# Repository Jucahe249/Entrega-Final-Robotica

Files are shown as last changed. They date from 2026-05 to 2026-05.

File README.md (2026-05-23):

En cada una de las carpetas hay una parte importante de Resqube

la carpeta RES contiene un modo de manejo de resqube que corresponde a una teleoperacion via teclado del pc y micro ros

la carpeta Resqube ensamblaje presenta todo el URDF de Resqube que fue necesario para su posterior implementacion en gazebo y en Rviz

El archivo comprimido Resqube.zip corresponde a esa configuracion en Gazebo y en Rviz donde se simulo a Resqube 

El archivo Resqube sin comprimir contiene los modelos cad de solid works que corresponden a los del Gazebo y Rviz

finalmente la carpeta resqube_ros2 corresponde a la alternativa principal de control de Resqube que es la teleoperacion por medio de una 
URL que se encarga de generar los comandos en Ros para que microros los interprete y se comunique con la ESP32

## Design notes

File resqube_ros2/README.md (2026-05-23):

# RESQUBE ROS2

## Estructura
```
resqube_ros2/
├── firmware/
│   ├── platformio.ini
│   └── resqube_firmware/
│       └── resqube_firmware.ino     ← flashear al ESP32
└── ros2_ws/
    └── src/resqube_ros2/
        ├── package.xml
        ├── CMakeLists.txt
        ├── resqube_ros2/
        │   ├── corridor_follower.py ← modo autónomo
        │   ├── teleop_joy.py        ← control por teclado
        │   └── alert_monitor.py     ← monitor de alertas
        ├── launch/
        │   └── resqube.launch.py    ← lanza todo
        └── config/
            └── rviz_resqube.rviz
```

## Requisitos
- ROS2 Humble
- micro-ROS Agent: `sudo apt install ros-humble-micro-ros-agent`
- PlatformIO con lib micro_ros_arduino
- ESP32 DevKit V1

## Instalación del workspace
```bash
cd ros2_ws
rosdep install --from-paths src --ignore-src -r -y
colcon build --packages-select resqube_ros2
source install/setup.bash
```

## Configurar el firmware
Editar en resqube_firmware.ino:
```cpp
#define WIFI_SSID  "TU_RED_WIFI"
#define WIFI_PASS  "TU_PASSWORD"
#define AGENT_IP   "192.168.1.100"   // IP de tu PC
#define AGENT_PORT 8888
```
Flashear con PlatformIO:
```bash
cd firmware
pio run --target upload
```

## Ejecutar
```bash
# Terminal 1 — todo de una vez:
ros2 launch resqube_ros2 resqube.launch.py

# O manualmente:
# T1 — agente
ros2 run micro_ros_agent micro_ros_agent udp4 --port 8888
# T2 — seguidor autónomo
ros2 run resqube_ros2 corridor_follower.py
# T3 — alertas
ros2 run resqube_ros2 alert_monitor.py
# T4 — teclado
ros2 run resqube_ros2 teleop_joy.py
```

## Verificar conexión
```bash
ros2 topic list          # debe mostrar /scan /cmd_vel /object_alert
ros2 topic hz /scan      # debe mostrar ~20 Hz
ros2 topic echo /scan    # ver datos en tiempo real
```

## Cambiar modo desde terminal
```bash
# Activar autónomo
ros2 service call /corridor_follower/activate std_srvs/srv/SetBool "{data: true}"
# Volver a remoto
ros2 service call /corridor_follower/activate std_srvs/srv/SetBool "{data: false}"
```

## Teleop desde teclado (en teleop_joy.py)
  W/S = adelante/atrás
  A/D = izquierda/derecha
  ESPACIO = stop
  X = activar servo
  M = toggle modo autónomo
  Q = salir

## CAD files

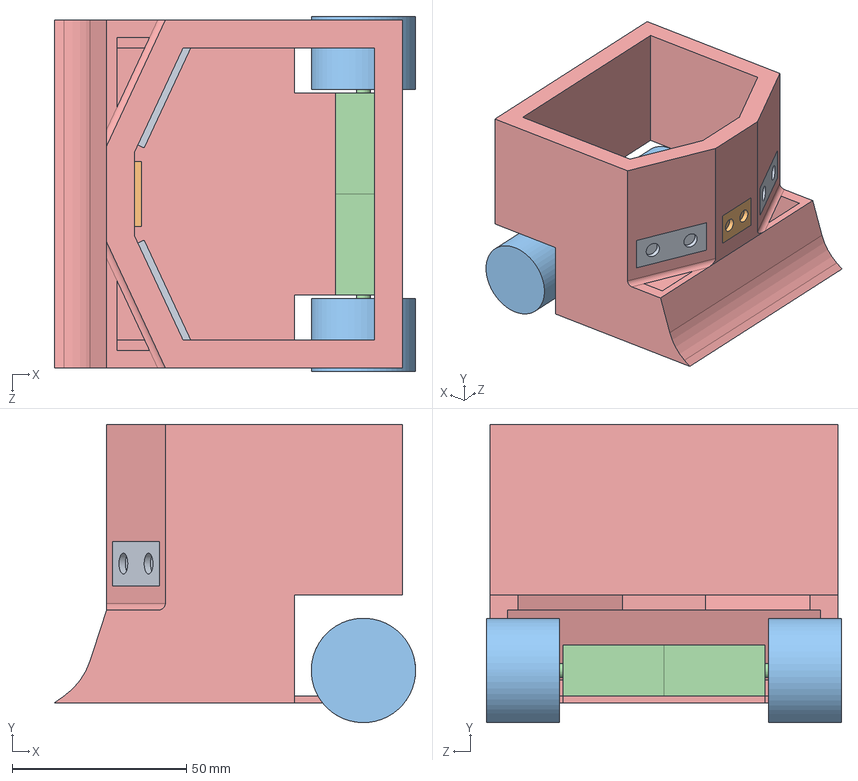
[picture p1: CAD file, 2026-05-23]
Resqube/Resqube.SLDASM
103.8 x 85.7 x 102.0 mm
Futsumo2
motor_resqube x 2
Rueda_resqube x 2
Sensor_frontal
Sensor_lateral x 2

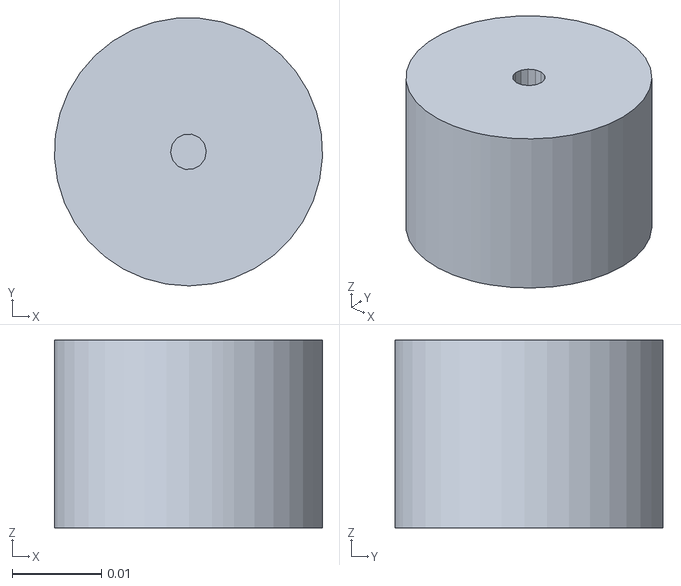
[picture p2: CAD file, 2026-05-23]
Resqube/Resqube_ensamblaje/meshes/rueda_izq_Link.STL
0.03 x 0.03 x 0.021

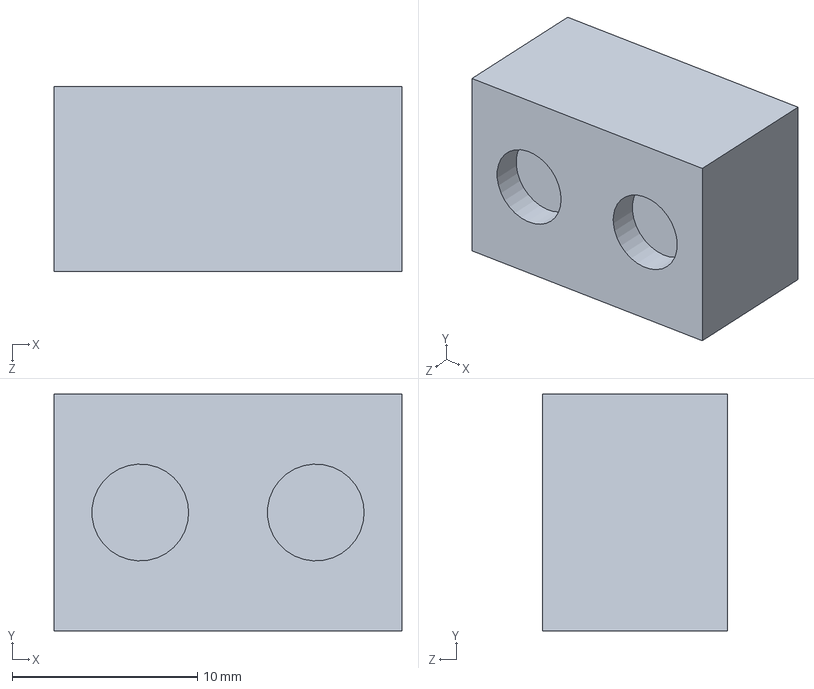
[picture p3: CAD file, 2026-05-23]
Resqube/Sensor_frontal.SLDPRT
18.8 x 12.8 x 10.0 mm

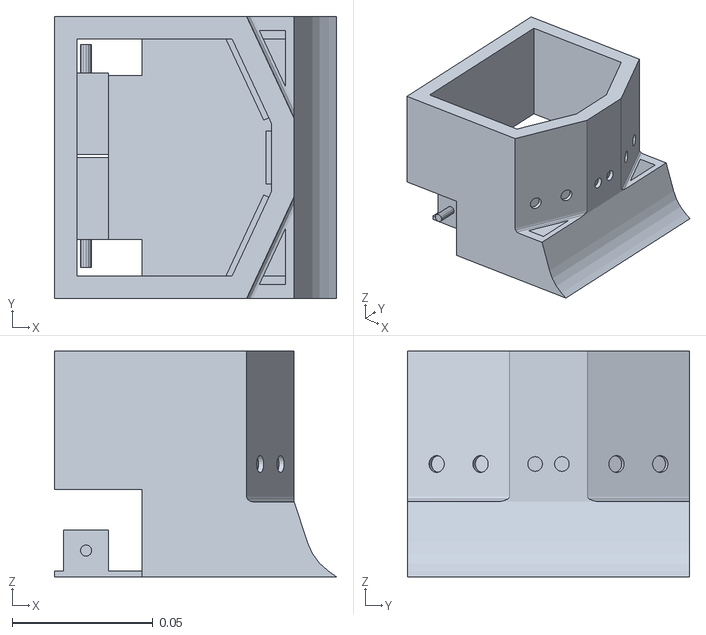
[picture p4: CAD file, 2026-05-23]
Resqube/Resqube_ensamblaje/meshes/base_link.STL
0.1 x 0.1 x 0.08

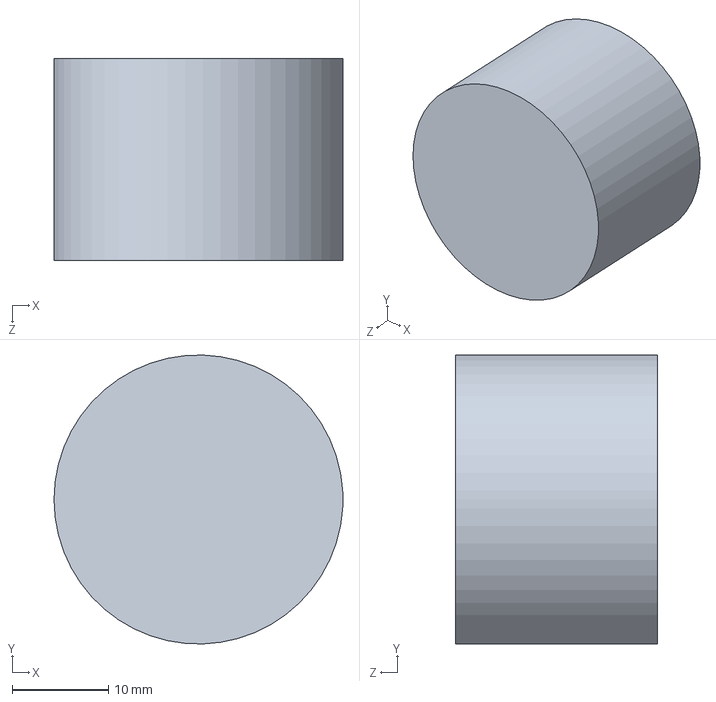
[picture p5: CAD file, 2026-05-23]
Resqube/Rueda_resqube.SLDPRT
30.0 x 30.0 x 21.0 mm

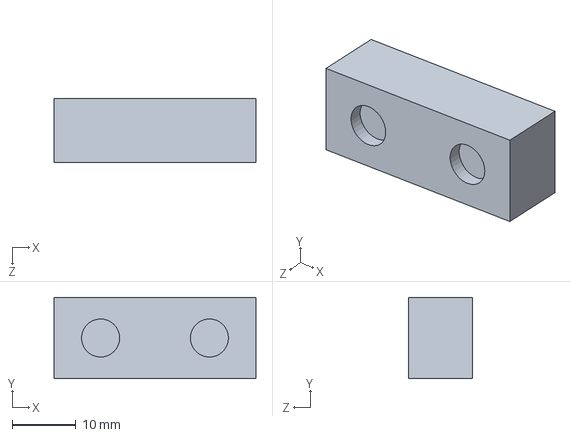
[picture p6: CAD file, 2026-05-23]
Resqube/Sensor_lateral.SLDPRT
31.8 x 12.8 x 10.0 mm

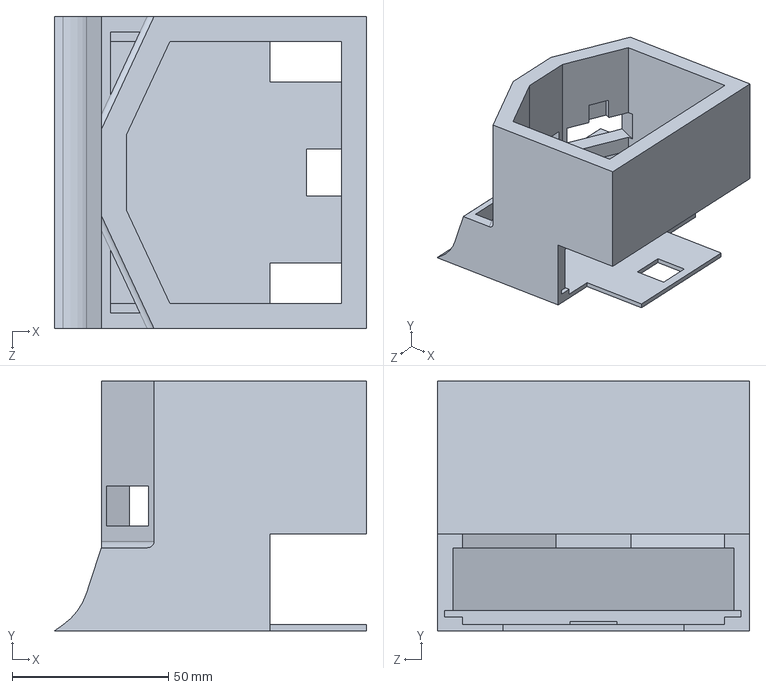
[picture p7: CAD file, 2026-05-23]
Resqube/Futsumo2.SLDPRT
100.0 x 80.0 x 100.0 mm

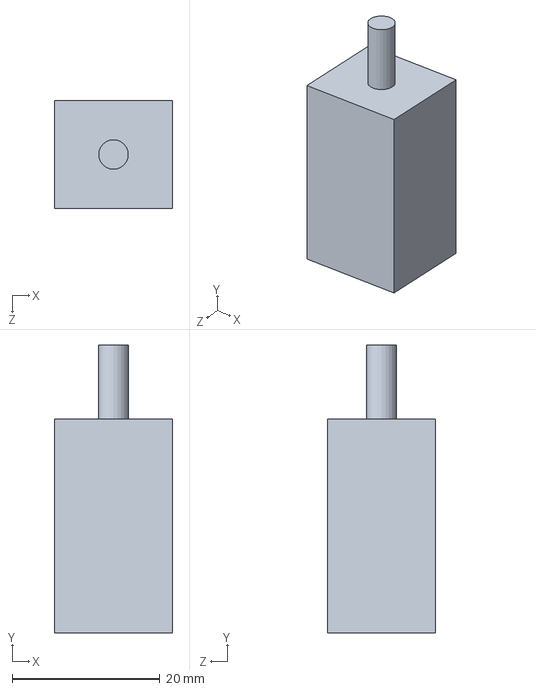
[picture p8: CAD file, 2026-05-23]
Resqube/motor_resqube.SLDPRT
16.0 x 39.0 x 14.6 mm

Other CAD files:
Resqube/Resqube_ensamblaje.SLDASM
Resqube/Resqube_ensamblaje/meshes/rueda_der_Link.STL

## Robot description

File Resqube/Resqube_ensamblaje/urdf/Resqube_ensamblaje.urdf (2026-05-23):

<?xml version="1.0" encoding="utf-8"?>
<!-- This URDF was automatically created by SolidWorks to URDF Exporter! Originally created by Stephen Brawner (brawner@gmail.com) 
     Commit Version: 1.6.0-4-g7f85cfe  Build Version: 1.6.7995.38578
     For more information, please see http://wiki.ros.org/sw_urdf_exporter -->
<robot name="Resqube_ensamblaje">
  <link name="base_link">
    <inertial>
      <origin xyz="-0.0077226 2.2038E-05 0.039426" rpy="0 0 0" />
      <mass value="0.18039" />
      <inertia ixx="0.00029984" ixy="5.4554E-08" ixz="3.0558E-05" iyy="0.00023582" iyz="-1.1356E-07" izz="0.00035246" />
    </inertial>
    <visual>
      <origin xyz="0 0 0" rpy="0 0 0" />
      <geometry>
        <mesh filename="package://Resqube_ensamblaje/meshes/base_link.STL" />
      </geometry>
      <material name="">
        <color rgba="0.79216 0.81961 0.93333 1" />
      </material>
    </visual>
    <collision>
      <origin xyz="0 0 0" rpy="0 0 0" />
      <geometry>
        <mesh filename="package://Resqube_ensamblaje/meshes/base_link.STL" />
      </geometry>
    </collision>
  </link>
  <link name="rueda_der_Link">
    <inertial>
      <origin xyz="3.8164E-17 -6.9389E-18 -0.009453" rpy="0 0 0" />
      <mass value="0.014718" />
      <inertia ixx="1.3755E-06" ixy="-1.0588E-22" ixz="-4.412E-23" iyy="1.3755E-06" iyz="2.7363E-23" izz="1.6697E-06" />
    </inertial>
    <visual>
      <origin xyz="0 0 0" rpy="0 0 0" />
      <geometry>
        <mesh filename="package://Resqube_ensamblaje/meshes/rueda_der_Link.STL" />
      </geometry>
      <material name="">
        <color rgba="0.79216 0.81961 0.93333 1" />
      </material>
    </visual>
    <collision>
      <origin xyz="0 0 0" rpy="0 0 0" />
      <geometry>
        <mesh filename="package://Resqube_ensamblaje/meshes/rueda_der_Link.STL" />
      </geometry>
    </collision>
  </link>
  <joint name="rueda_der_joint" type="continuous">
    <origin xyz="-0.038712 -0.05 0.0073" rpy="1.5708 -0.59492 0" />
    <parent link="base_link" />
    <child link="rueda_der_Link" />
    <axis xyz="0 0 1" />
    <limit effort="100" velocity="100" />
    <dynamics damping="0.1" friction="0.1" />
  </joint>
  <link name="rueda_izq_Link">
    <inertial>
      <origin xyz="1.3878E-17 -2.6021E-17 -0.010547" rpy="0 0 0" />
      <mass value="0.014718" />
      <inertia ixx="1.3755E-06" ixy="0" ixz="1.0421E-22" iyy="1.3755E-06" iyz="-1.2799E-22" izz="1.6697E-06" />
    </inertial>
    <visual>
      <origin xyz="0 0 0" rpy="0 0 0" />
      <geometry>
        <mesh filename="package://Resqube_ensamblaje/meshes/rueda_izq_Link.STL" />
      </geometry>
      <material name="">
        <color rgba="0.79216 0.81961 0.93333 1" />
      </material>
    </visual>
    <collision>
      <origin xyz="0 0 0" rpy="0 0 0" />
      <geometry>
        <mesh filename="package://Resqube_ensamblaje/meshes/rueda_izq_Link.STL" />
      </geometry>
    </collision>
  </link>
  <joint name="rueda_izq_joint" type="continuous">
    <origin xyz="-0.038712 0.031 0.0073" rpy="1.5708 1.3691 0" />
    <parent link="base_link" />
    <child link="rueda_izq_Link" />
    <axis xyz="0 0 -1" />
    <limit effort="100" velocity="100" />
    <dynamics damping="0.1" friction="0.1" />
  </joint>
</robot>

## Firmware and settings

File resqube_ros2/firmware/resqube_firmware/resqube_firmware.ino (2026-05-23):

/*
  ============================================
  RESQUBE - ESP32 DevKit V1
  micro-ROS client para ROS2 Humble
  Transport: WiFi UDP
  ============================================
  Topics publicados:
    /scan          sensor_msgs/LaserScan  (3 rayos Sharp)
    /line_sensor   std_msgs/Int32         (QTR raw)
    /object_alert  std_msgs/Bool          (sin paredes)
    /odom          nav_msgs/Odometry      (estimación básica)

  Topics suscritos:
    /cmd_vel       geometry_msgs/Twist
    /servo_cmd     std_msgs/Bool

  Servicios:
    /set_mode      std_srvs/SetBool       (true=AUTONOMO)
  ============================================
*/

#include <micro_ros_arduino.h>
#include <stdio.h>
#include <rcl/rcl.h>
#include <rcl/error_handling.h>
#include <rclc/rclc.h>
#include <rclc/executor.h>

#include <geometry_msgs/msg/twist.h>
#include <sensor_msgs/msg/laser_scan.h>
#include <std_msgs/msg/int32.h>
#include <std_msgs/msg/bool.h>
#include <nav_msgs/msg/odometry.h>
#include <std_srvs/srv/set_bool.h>

#include <ESP32Servo.h>

// ─── WIFI / AGENTE ────────────────────────────────────
#define WIFI_SSID   "TU_RED_WIFI"
#define WIFI_PASS   "TU_PASSWORD"
#define AGENT_IP    "192.168.251.131"   // IP de tu PC con el agente
#define AGENT_PORT  8888

// ─── PINES MOTOR A ────────────────────────────────────
#define PWMA   33
#define AIN1   14
#define AIN2   27

// ─── PINES MOTOR B ────────────────────────────────────
#define PWMB   32
#define BIN1   26
#define BIN2   25

// ─── SENSORES SHARP ───────────────────────────────────
#define SENSOR_IZQ     4
#define SENSOR_FRENTE  18
#define SENSOR_DER     19

// ─── SENSOR LÍNEA ─────────────────────────────────────
#define LINEA_DEL  35

// ─── OTROS ────────────────────────────────────────────
#define STBY      12
#define LED_PIN    2
#define SERVO_PIN 13

// ─── PWM ──────────────────────────────────────────────
#define PWM_FREQ    1000
#define PWM_RES     8
#define CHANNEL_A   0
#define CHANNEL_B   1

// ─── VELOCIDADES ──────────────────────────────────────
#define VEL_AVANCE      200
#define VEL_GIRO        180
#define VEL_CORRECCION  160
#define VEL_RETRO       200

// ─── UMBRAL QTR ───────────────────────────────────────
#define UMBRAL_QTR 2000

// ─── DISTANCIAS SHARP (metros) ────────────────────────
// GP2Y0A21 detecta ~10-80 cm. HIGH = objeto detectado
#define DIST_DETECTED   0.15f   // objeto a ~15 cm
#define DIST_CLEAR      1.0f    // pasillo libre

// ─── PUBLICACIÓN ──────────────────────────────────────
#define PUB_PERIOD_MS   50      // 20 Hz

// ─── micro-ROS handles ────────────────────────────────
rcl_node_t           node;
rclc_support_t       support;
rcl_allocator_t      allocator;
rclc_executor_t      executor;
rcl_timer_t          pub_timer;

rcl_subscription_t   sub_cmdvel;
rcl_subscription_t   sub_servo;
rcl_publisher_t      pub_scan;
rcl_publisher_t      pub_line;
rcl_publisher_t      pub_alert;
rcl_publisher_t      pub_odom;
rcl_service_t        srv_setmode;

geometry_msgs__msg__Twist          msg_cmdvel;
std_msgs__msg__Bool                msg_servo;
sensor_msgs__msg__LaserScan        msg_scan;
std_msgs__msg__Int32               msg_line;
std_msgs__msg__Bool                msg_alert;
nav_msgs__msg__Odometry            msg_odom;
std_srvs__srv__SetBool_Request     req_setmode;
std_srvs__srv__SetBool_Response    res_setmode;

// Buffer para LaserScan (3 rayos)
float scan_ranges[3];
float scan_intensities[3];

// ─── ESTADO ───────────────────────────────────────────
bool modoAutonomo = false;
bool alertaObjeto = false;
Servo miServo;

// ─── MACROS RCCHECK ───────────────────────────────────
#define RCCHECK(fn) { rcl_ret_t temp_rc = fn; if(temp_rc != RCL_RET_OK){ error_loop(); }}
#define RCSOFTCHECK(fn) { rcl_ret_t temp_rc = fn; if(temp_rc != RCL_RET_OK){} }

void error_loop() {
  while(1) {
    digitalWrite(LED_PIN, !digitalRead(LED_PIN));
    delay(100);
  }
}

// ══════════════════════════════════════════════════════
//  MOTORES (igual que antes)
// ══════════════════════════════════════════════════════

void motorsInit() {
  pinMode(AIN1, OUTPUT); pinMode(AIN2, OUTPUT);
  pinMode(BIN1, OUTPUT); pinMode(BIN2, OUTPUT);
  pinMode(STBY, OUTPUT);
  ledcSetup(CHANNEL_A, PWM_FREQ, PWM_RES);
  ledcAttachPin(PWMA, CHANNEL_A);
  ledcSetup(CHANNEL_B, PWM_FREQ, PWM_RES);
  ledcAttachPin(PWMB, CHANNEL_B);
  digitalWrite(STBY, HIGH);
}

void motorA_adelante(int v) { digitalWrite(AIN1,LOW);  digitalWrite(AIN2,HIGH); ledcWrite(CHANNEL_A,v); }
void motorA_atras(int v)    { digitalWrite(AIN1,HIGH); digitalWrite(AIN2,LOW);  ledcWrite(CHANNEL_A,v); }
void motorA_stop()          { digitalWrite(AIN1,LOW);  digitalWrite(AIN2,LOW);  ledcWrite(CHANNEL_A,0); }
void motorB_adelante(int v) { digitalWrite(BIN1,LOW);  digitalWrite(BIN2,HIGH); ledcWrite(CHANNEL_B,v); }
void motorB_atras(int v)    { digitalWrite(BIN1,HIGH); digitalWrite(BIN2,LOW);  ledcWrite(CHANNEL_B,v); }
void motorB_stop()          { digitalWrite(BIN1,LOW);  digitalWrite(BIN2,LOW);  ledcWrite(CHANNEL_B,0); }

void moverAdelante(int v) { motorA_atras(v);    motorB_atras(v);    }
void moverAtras(int v)    { motorA_adelante(v); motorB_adelante(v); }
void girarIzq(int v)      { motorA_atras(v);    motorB_adelante(v); }
void girarDer(int v)      { motorA_adelante(v); motorB_atras(v);    }
void stopMotors()         { motorA_stop();      motorB_stop();      }

// Convierte Twist a comandos de motor
void aplicarTwist(float linear, float angular) {
  if (linear > 0.05f)        moverAdelante(VEL_AVANCE);
  else if (linear < -0.05f)  moverAtras(VEL_AVANCE);
  else if (angular > 0.05f)  girarIzq(VEL_GIRO);
  else if (angular < -0.05f) girarDer(VEL_GIRO);
  else                       stopMotors();
}

// ══════════════════════════════════════════════════════
//  SERVO
// ══════════════════════════════════════════════════════

void toggleServo() {
  miServo.attach(SERVO_PIN, 600, 2400);
  delay(50);
  miServo.writeMicroseconds(1600);
  delay(400);
  miServo.writeMicroseconds(1500);
  delay(400);
  miServo.detach();
}

// ══════════════════════════════════════════════════════
//  CALLBACKS micro-ROS
// ══════════════════════════════════════════════════════

// Llega /cmd_vel (solo actúa en modo REMOTO)
void cmdvel_callback(const void * msgin) {
  if (modoAutonomo) return;
  const geometry_msgs__msg__Twist * msg =
    (const geometry_msgs__msg__Twist *)msgin;
  aplicarTwist(msg->linear.x, msg->angular.z);
}

// Llega /servo_cmd
void servo_callback(const void * msgin) {
  const std_msgs__msg__Bool * msg =
    (const std_msgs__msg__Bool *)msgin;
  if (msg->data) toggleServo();
}

// Servicio /set_mode (true = autónomo, false = remoto)
void setmode_callback(const void * req, void * res) {
  std_srvs__srv__SetBool_Request  * r =
    (std_srvs__srv__SetBool_Request  *)req;
  std_srvs__srv__SetBool_Response * s =
    (std_srvs__srv__SetBool_Response *)res;
  modoAutonomo = r->data;
  if (!modoAutonomo) stopMotors();
  s->success = true;
  rosidl_runtime_c__String__assignn(
    &s->message,
    modoAutonomo ? "Modo AUTONOMO" : "Modo REMOTO",
    modoAutonomo ? 13 : 12);
}

// Timer de publicación (50 ms)
void pub_timer_callback(rcl_timer_t * timer, int64_t last_call_time) {
  RCLC_UNUSED(last_call_time);
  if (timer == NULL) return;

  int64_t stamp_ns = rmw_uros_epoch_nanos();

  // ── /scan ──────────────────────────────────────────
  bool sIzq    = digitalRead(SENSOR_IZQ)    == HIGH;
  bool sFrente = digitalRead(SENSOR_FRENTE) == HIGH;
  bool sDer    = digitalRead(SENSOR_DER)    == HIGH;

  scan_ranges[0] = sIzq    ? DIST_DETECTED : DIST_CLEAR;
  scan_ranges[1] = sFrente ? DIST_DETECTED : DIST_CLEAR;
  scan_ranges[2] = sDer    ? DIST_DETECTED : DIST_CLEAR;

  msg_scan.header.stamp.sec     = (int32_t)(stamp_ns / 1000000000LL);
  msg_scan.header.stamp.nanosec = (uint32_t)(stamp_ns % 1000000000LL);
  msg_scan.angle_min    = -1.5708f;  // -90°
  msg_scan.angle_max    =  1.5708f;  //  90°
  msg_scan.angle_increment = 1.5708f;// 90° entre rayos
  msg_scan.range_min    = 0.10f;
  msg_scan.range_max    = 1.00f;
  msg_scan.ranges.data  = scan_ranges;
  msg_scan.ranges.size  = 3;
  msg_scan.ranges.capacity = 3;
  RCSOFTCHECK(rcl_publish(&pub_scan, &msg_scan, NULL));

  // ── /line_sensor ───────────────────────────────────
  msg_line.data = analogRead(LINEA_DEL);
  RCSOFTCHECK(rcl_publish(&pub_line, &msg_line, NULL));

  // ── /object_alert ──────────────────────────────────
  alertaObjeto = (!sIzq && !sFrente && !sDer);
  msg_alert.data = alertaObjeto;
  RCSOFTCHECK(rcl_publish(&pub_alert, &msg_alert, NULL));

  // ── LED heartbeat ──────────────────────────────────
  digitalWrite(LED_PIN, !digitalRead(LED_PIN));
}

// ══════════════════════════════════════════════════════
//  SETUP
// ══════════════════════════════════════════════════════

void setup() {
  Serial.begin(115200);
  pinMode(LED_PIN,       OUTPUT);
  pinMode(SENSOR_IZQ,    INPUT);
  pinMode(SENSOR_FRENTE, INPUT);
  pinMode(SENSOR_DER,    INPUT);
  pinMode(LINEA_DEL,     INPUT);

  miServo.attach(SERVO_PIN, 600, 2400);
  miServo.writeMicroseconds(1500);
  delay(300);
  miServo.detach();

  motorsInit();

  // Conectar al agente micro-ROS vía WiFi
  set_microros_wifi_transports((char*)WIFI_SSID, (char*)WIFI_PASS, (char*)AGENT_IP, AGENT_PORT);
  delay(2000);

  allocator = rcl_get_default_allocator();
  RCCHECK(rclc_support_init(&support, 0, NULL, &allocator));
  RCCHECK(rclc_node_init_default(&node, "resqube", "", &support));

  // Sincronizar tiempo con el agente
  RCCHECK(rmw_uros_sync_session(1000));

  // ── Publishers ──────────────────────────────────────
  RCCHECK(rclc_publisher_init_default(&pub_scan,  &node,
    ROSIDL_GET_MSG_TYPE_SUPPORT(sensor_msgs, msg, LaserScan), "/scan"));
  RCCHECK(rclc_publisher_init_default(&pub_line,  &node,
    ROSIDL_GET_MSG_TYPE_SUPPORT(std_msgs, msg, Int32), "/line_sensor"));
  RCCHECK(rclc_publisher_init_default(&pub_alert, &node,
    ROSIDL_GET_MSG_TYPE_SUPPORT(std_msgs, msg, Bool), "/object_alert"));
  RCCHECK(rclc_publisher_init_default(&pub_odom,  &node,
    ROSIDL_GET_MSG_TYPE_SUPPORT(nav_msgs, msg, Odometry), "/odom"));

  // ── Subscribers ─────────────────────────────────────
  RCCHECK(rclc_subscription_init_default(&sub_cmdvel, &node,
    ROSIDL_GET_MSG_TYPE_SUPPORT(geometry_msgs, msg, Twist), "/cmd_vel"));
  RCCHECK(rclc_subscription_init_default(&sub_servo, &node,
    ROSIDL_GET_MSG_TYPE_SUPPORT(std_msgs, msg, Bool), "/servo_cmd"));

  // ── Servicio ────────────────────────────────────────
  RCCHECK(rclc_service_init_default(&srv_setmode, &node,
    ROSIDL_GET_SRV_TYPE_SUPPORT(std_srvs, srv, SetBool), "/set_mode"));

  // ── Timer de publicación ────────────────────────────
  RCCHECK(rclc_timer_init_default2(&pub_timer, &support,
    RCL_MS_TO_NS(PUB_PERIOD_MS), pub_timer_callback, true));

  // ── Executor (1 timer + 2 subs + 1 srv = 4 handles) ─
  RCCHECK(rclc_executor_init(&executor, &support.context, 4, &allocator));
  RCCHECK(rclc_executor_add_timer(&executor, &pub_timer));
  RCCHECK(rclc_executor_add_subscription(&executor, &sub_cmdvel,
    &msg_cmdvel, &cmdvel_callback, ON_NEW_DATA));
  RCCHECK(rclc_executor_add_subscription(&executor, &sub_servo,
    &msg_servo, &servo_callback, ON_NEW_DATA));
  RCCHECK(rclc_executor_add_service(&executor, &srv_setmode,
    &req_setmode, &res_setmode, &setmode_callback));

  // Parpadeo OK
  for (int i = 0; i < 5; i++) {
    digitalWrite(LED_PIN, HIGH); delay(100);
    digitalWrite(LED_PIN, LOW);  delay(100);
  }
  Serial.println("[RESQUBE] micro-ROS listo");
}

// ══════════════════════════════════════════════════════
//  LOOP
// ══════════════════════════════════════════════════════

void loop() {
  rclc_executor_spin_some(&executor, RCL_MS_TO_NS(10));
}
